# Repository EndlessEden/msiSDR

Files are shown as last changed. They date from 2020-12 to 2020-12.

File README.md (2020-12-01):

this is an Software Define Radio receiver PCB project base on msi2500 and msi001. use kicad to view it

这是一个基于msi2500 和 msi001的软件无线电PCB工程项目， 使用kiCAD浏览此工程

如果需要PCB打样，把gerber目录下的文件发给PCB加工厂即可

Send gerbar files to PCB factory . you'd better to use SMT

建议叫工厂SMT贴片，手动焊接容易太多bug

软件使用SDRuno（选SDRPlay）

software compatible with SDRplay

## Updates from NaiveTomcat
在原版的基础上增加了一个U.FL接口用于L波段天线的连接（才不会说是懒得重新
布线才用U.FL接口的呢）Gerber文件在Gerberv3目录

Added a U.FL Male socket onto the PCB for aerials for L-Band.
(Used U.FL for its size can fit inside the board with no need
to redo the route) Gerber files are in the Gerberv3 directory.

使用效果

PCB

SDR

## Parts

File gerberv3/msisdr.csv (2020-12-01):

ID | 位号 | 包 | 数量 | 名称 | 供应商和位号
1 | J12 | U.FL_Molex_MCRF_73412-0110_Vertical | 1 | Conn_01x02
2 | C43 | C_0603_1608Metric_Pad1.08x0.95mm_HandSolder | 1 | 10nF
3 | REF**,REF**,REF**,REF** | 1pin | 4 | 1pin
4 | C1,C11,C12,C13,C14,C15,C19,C20,C21,C24,C25,C26,C42 | C_0603 | 13 | 10nF
5 | C2,C3,C4,C5,C7,C36,C37,C38 | C_0805 | 8 | 10uF
6 | C6,C8,C18 | C_0805 | 3 | 1uF
7 | C9,C10 | C_0603 | 2 | 18pF
8 | C16,C17 | C_0603 | 2 | 100nF
9 | C22 | C_0603 | 1 | 6800pF
10 | C23 | C_0603 | 1 | 33nF
11 | C27 | C_0805 | 1 | 470nF
12 | C28 | C_0603 | 1 | 1nF
13 | C29,C34 | C_0603 | 2 | 56pF
14 | C30 | C_0603 | 1 | 3.9pF
15 | C31,C33 | C_0603 | 2 | 160pF
16 | C32 | C_0603 | 1 | 39pF
17 | C35 | CP_Radial_D5.0mm_P2.50mm | 1 | 100uF
18 | J6 | SMA_OPL_EM | 1 | SMA_0_30MHZ
19 | J7 | SMA_OPL_EM | 1 | SMA_30_60MHZ
20 | J8 | SMA_OPL_EMPTYHEAD | 1 | SMA_VHF2
21 | J9 | SMA_OPL_EMPTYHEAD | 1 | SMA_UHF
22 | J10 | SMA_OPL_EMPTYHEAD | 1 | SMA_VHF1
23 | J11 | USB_Mini-B | 1 | USB_OTG
24 | L1 | L_0805 | 1 | 220nH
25 | L2,L3,L6 | L_0805 | 3 | 330nH
26 | L4 | L_0805 | 1 | 270nH
27 | L5 | L_0805 | 1 | 150nH
28 | R1 | R_0603 | 1 | 510R
29 | R2 | R_0603 | 1 | 390R
30 | U1 | QFN-32-1EP_5x5mm_Pitch0.5mm | 1 | msi2500
31 | U2 | QFN-40-1EP_6x6mm_Pitch0.5mm | 1 | msi001
32 | Y1 | Crystal_HC50_Vertical | 1 | 24MHz
33 | J1 | Pin_d0.7mm_L6.5mm_W1.8mm_FlatFork | 1 | VCC_GPIO
34 | J2 | Pin_d0.7mm_L6.5mm_W1.8mm_FlatFork | 1 | GPIO0
35 | J3 | Pin_d0.7mm_L6.5mm_W1.8mm_FlatFork | 1 | GPIO1
36 | J4 | Pin_d0.7mm_L6.5mm_W1.8mm_FlatFork | 1 | GPIO2
37 | J5 | Pin_d0.7mm_L6.5mm_W1.8mm_FlatFork | 1 | GPIO3
38 | C39,C41 | C_0805 | 2 | 1UF
39 | D5 | D_DO-35_SOD27_P2.54mm_Vertical_AnodeUp | 1 | LED
40 | R3 | R_0603 | 1 | 512
41 | C40 | C_0603 | 1 | 22nF
42 | R4,R5,R6,R7,R8 | R_0603 | 5 | 10K
43 | U3 | SOT-23-5 | 1 | RT9193-28
44 | U4 | SOT-23 | 1 | AP7313-30SAG
45 | Y2 | Crystal_SMD_7050-4pin_7.0x5.0mm | 1 | 24MHZ
46 | D1,D2 | SOT-23 | 2 | BAV99LT1G
47 | REF*** | KiCad-Logo2_6mm_SilkScreen | 1 | KiCad-Logo2_6mm_SilkScreen
48 | REF*** | WEEE-Logo_5.6x8mm_SilkScreen | 1 | WEEE-Logo_5.6x8mm_SilkScreen

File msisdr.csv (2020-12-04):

ID | 位号 | 包 | 数量 | 名称 | 供应商和位号
1 | J10 | SMA_Samtec_SMA-J-P-X-ST-EM1_EdgeMount | 1 | SMA_VHF1
2 | J8 | SMA_Samtec_SMA-J-P-X-ST-EM1_EdgeMount | 1 | SMA_VHF2
3 | Y2 | Crystal_SMD_7050-4Pin_7.0x5.0mm | 1 | 24MHZ
4 | Y1 | Crystal_HC50_Vertical | 1 | 24MHz
5 | U4 | SOT-23 | 1 | AP7313-30SAG
6 | U3 | SOT-23-5 | 1 | RT9193-28
7 | U2 | QFN-40-1EP_6x6mm_P0.5mm_EP4.6x4.6mm_ThermalVias | 1 | msi001
8 | U1 | QFN-32-1EP_5x5mm_P0.5mm_EP3.7x3.7mm_ThermalVias | 1 | msi2500
9 | R8,R7,R6,R5,R4 | R_1206_3216Metric_Pad1.30x1.75mm_HandSolder | 5 | 10K
10 | R3 | R_1206_3216Metric_Pad1.30x1.75mm_HandSolder | 1 | 512
11 | R2 | R_1206_3216Metric_Pad1.30x1.75mm_HandSolder | 1 | 390R
12 | R1 | R_1206_3216Metric_Pad1.30x1.75mm_HandSolder | 1 | 510R
13 | L6,L3,L2 | L_1206_3216Metric_Pad1.42x1.75mm_HandSolder | 3 | 330nH
14 | L5 | L_1206_3216Metric_Pad1.42x1.75mm_HandSolder | 1 | 150nH
15 | L4 | L_1206_3216Metric_Pad1.42x1.75mm_HandSolder | 1 | 270nH
16 | L1 | L_1206_3216Metric_Pad1.42x1.75mm_HandSolder | 1 | 220nH
17 | J11 | USB_Micro-B_Wuerth_629105150521 | 1 | USB_OTG
18 | J9 | SMA_Samtec_SMA-J-P-X-ST-EM1_EdgeMount | 1 | SMA_UHF
19 | J7 | SMA_Samtec_SMA-J-P-X-ST-EM1_EdgeMount | 1 | SMA_30_60MHZ
20 | J6 | SMA_Samtec_SMA-J-P-X-ST-EM1_EdgeMount | 1 | SMA_0_30MHZ
21 | J5 | Pin_D0.7mm_L6.5mm_W1.8mm_FlatFork | 1 | GPIO3
22 | J4 | Pin_D0.7mm_L6.5mm_W1.8mm_FlatFork | 1 | GPIO2
23 | J3 | Pin_D0.7mm_L6.5mm_W1.8mm_FlatFork | 1 | GPIO1
24 | J2 | Pin_D0.7mm_L6.5mm_W1.8mm_FlatFork | 1 | GPIO0
25 | J1 | Pin_D0.7mm_L6.5mm_W1.8mm_FlatFork | 1 | VCC_GPIO
26 | D5 | D_DO-35_SOD27_P2.54mm_Vertical_AnodeUp | 1 | LED
27 | D2,D1 | SOT-23 | 2 | BAV99LT1G
28 | C43,C42,C26,C25,C24,C21,C20,C19,C15,C14,C13,C12,C11,C1 | C_1206_3216Metric_Pad1.33x1.80mm_HandSolder | 14 | 10nF
29 | C41,C39 | C_1206_3216Metric_Pad1.33x1.80mm_HandSolder | 2 | 1UF
30 | C40 | C_1206_3216Metric_Pad1.33x1.80mm_HandSolder | 1 | 22nF
31 | C38,C37,C36,C7,C5,C4,C3,C2 | C_1206_3216Metric_Pad1.33x1.80mm_HandSolder | 8 | 10uF
32 | C35 | CP_Radial_D5.0mm_P2.50mm | 1 | 100uF
33 | C34,C29 | C_1206_3216Metric_Pad1.33x1.80mm_HandSolder | 2 | 56pF
34 | C33,C31 | C_1206_3216Metric_Pad1.33x1.80mm_HandSolder | 2 | 160pF
35 | C32 | C_1206_3216Metric_Pad1.33x1.80mm_HandSolder | 1 | 39pF
36 | C30 | C_1206_3216Metric_Pad1.33x1.80mm_HandSolder | 1 | 3.9pF
37 | C28 | C_1206_3216Metric_Pad1.33x1.80mm_HandSolder | 1 | 1nF
38 | C27 | C_1206_3216Metric_Pad1.33x1.80mm_HandSolder | 1 | 470nF
39 | C23 | C_1206_3216Metric_Pad1.33x1.80mm_HandSolder | 1 | 33nF
40 | C22 | C_1206_3216Metric_Pad1.33x1.80mm_HandSolder | 1 | 6800pF
41 | C18,C8,C6 | C_1206_3216Metric_Pad1.33x1.80mm_HandSolder | 3 | 1uF
42 | C17,C16 | C_1206_3216Metric_Pad1.33x1.80mm_HandSolder | 2 | 100nF
43 | C10,C9 | C_1206_3216Metric_Pad1.33x1.80mm_HandSolder | 2 | 18pF
44 | J12 | U.FL_Molex_MCRF_73412-0110_Vertical | 1 | Conn_01x02
45 | REF**,REF**,REF**,REF** | 1pin | 4 | 1pin

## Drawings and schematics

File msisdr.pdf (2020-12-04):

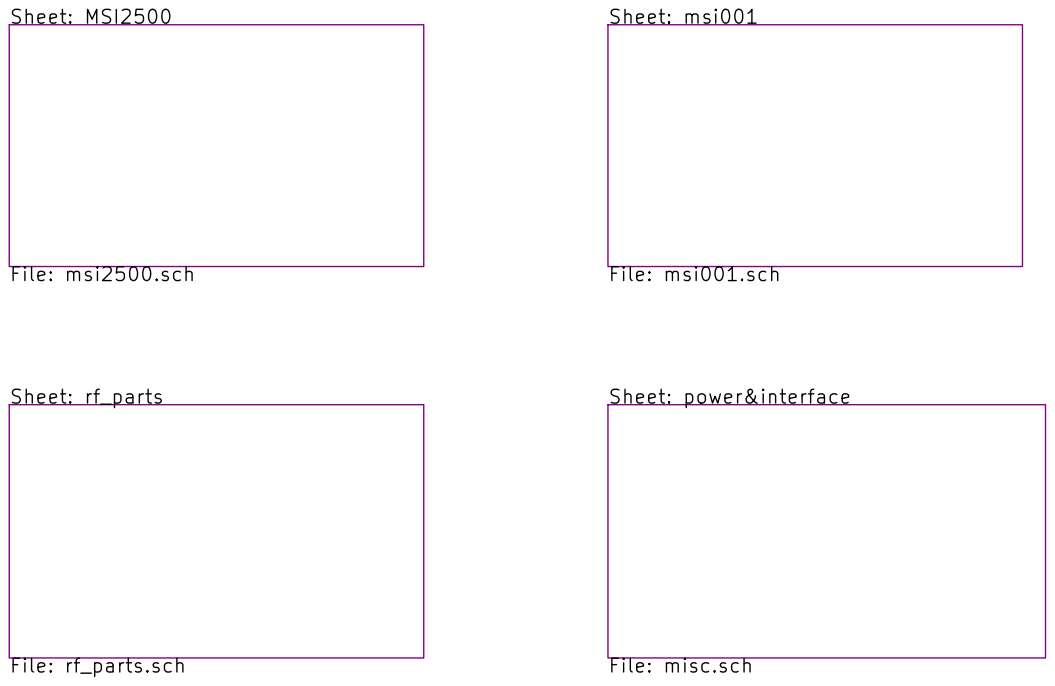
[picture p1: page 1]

Sheet: power&interface File: misc.sch

Id: 1/5 Title: File: msisdr.sch Sheet: /

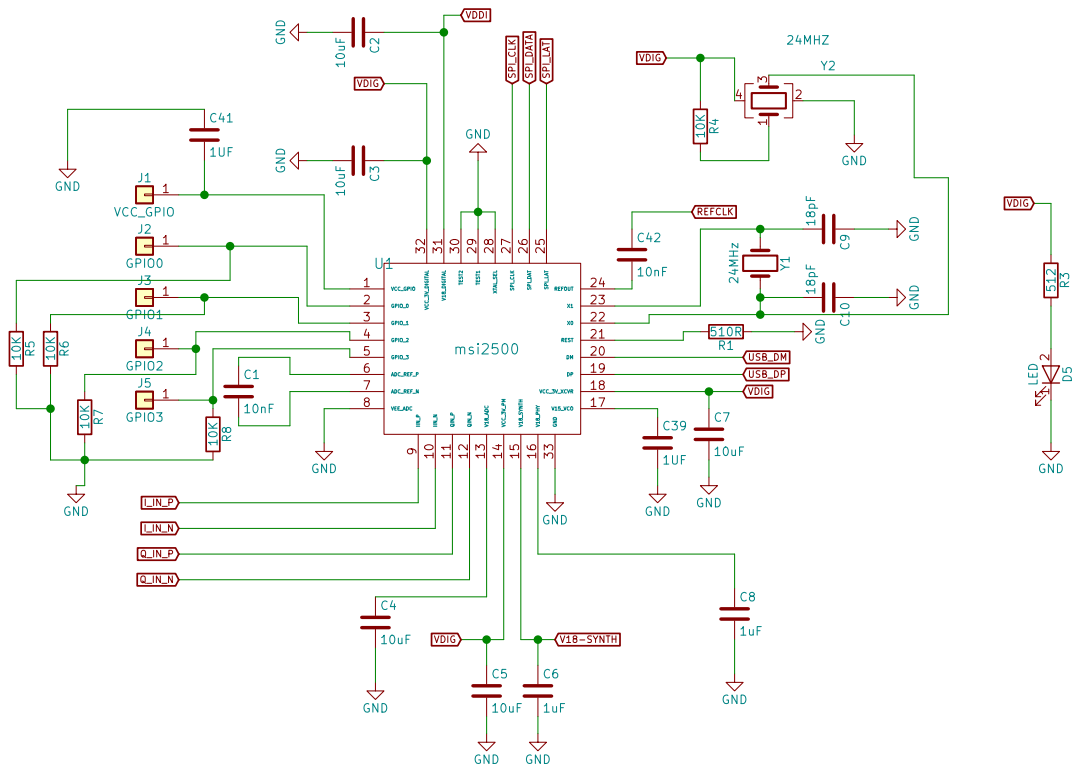
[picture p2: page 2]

Id: 2/5 Title: File: msi2500.sch Sheet: /MSI2500/ C6

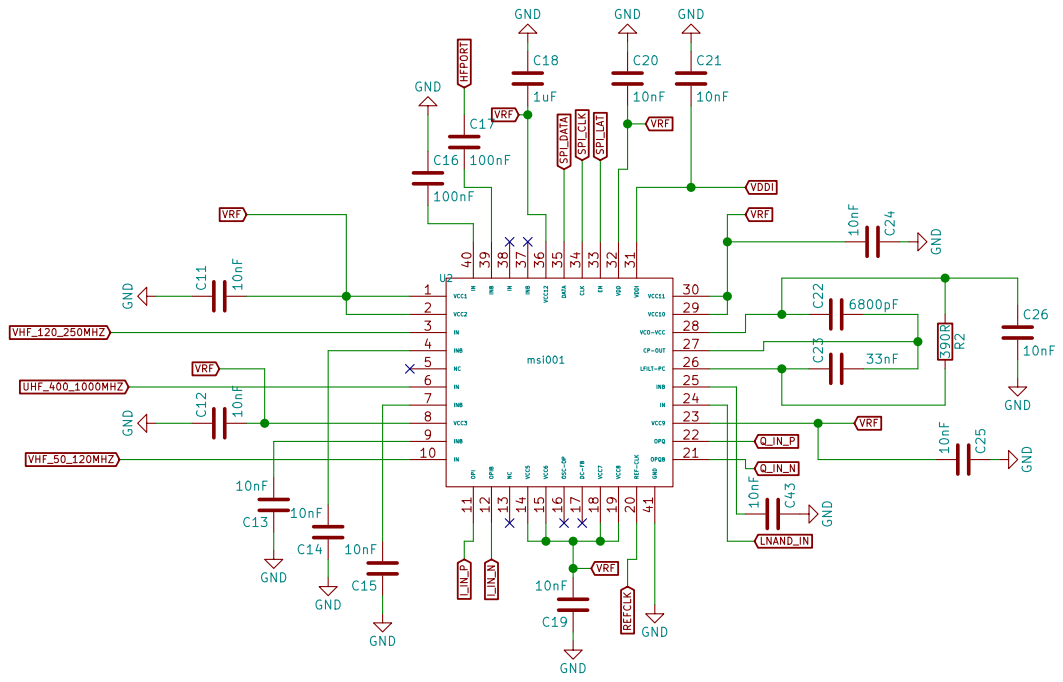
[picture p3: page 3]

Id: 3/5 Title: File: msi001.sch Sheet: /msi001/

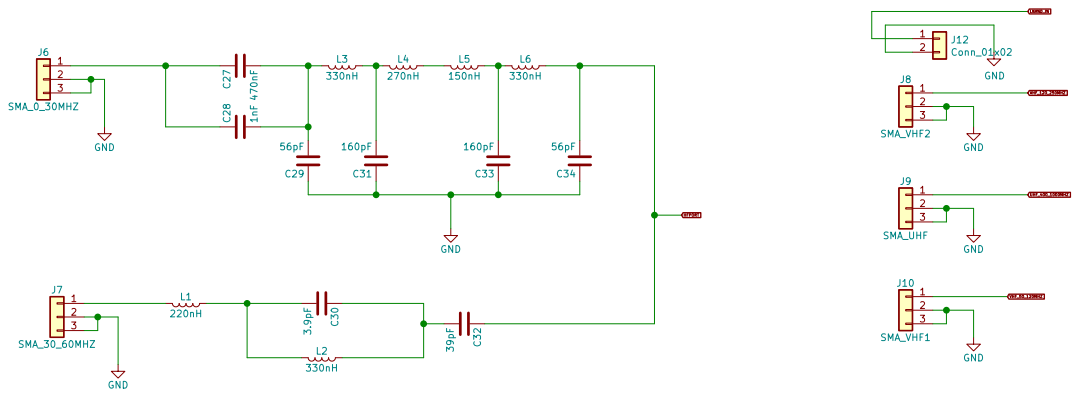
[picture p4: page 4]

2 | 470nF 56pF C27

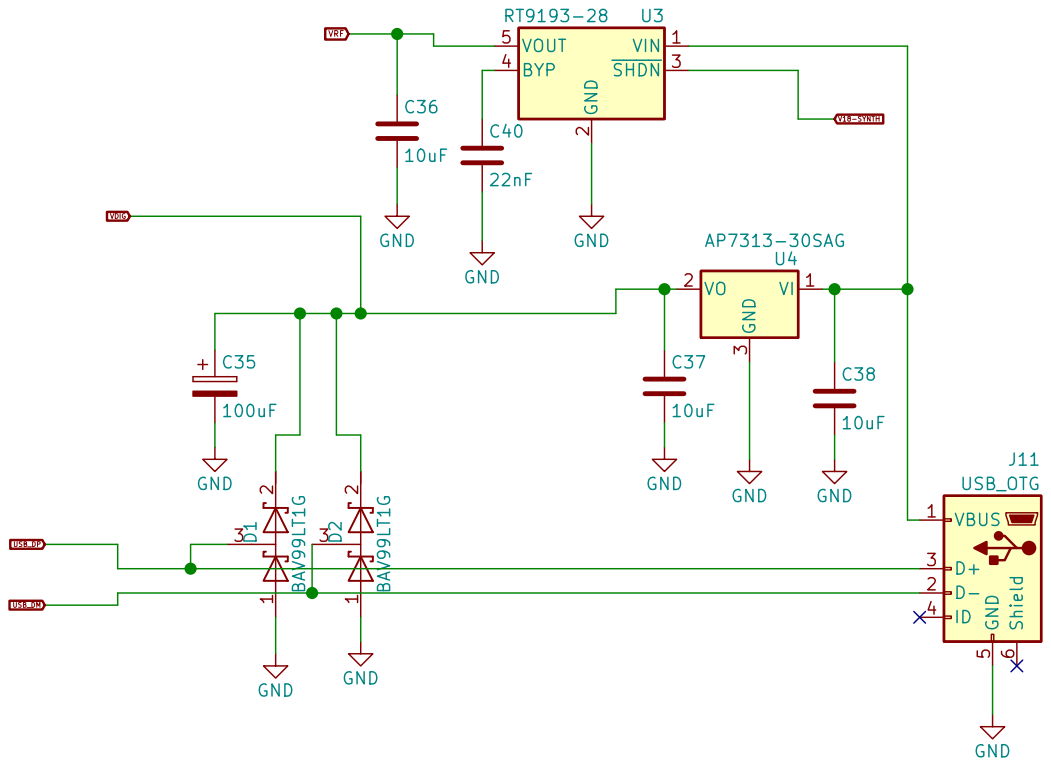
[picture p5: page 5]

2 SHDN 3 BYP 4 VOUT 5 RT9193-28 U3 VI 1 VO 2 GND

Id: 5/5 Title: File: misc.sch Sheet: /power&interface/ GND GND

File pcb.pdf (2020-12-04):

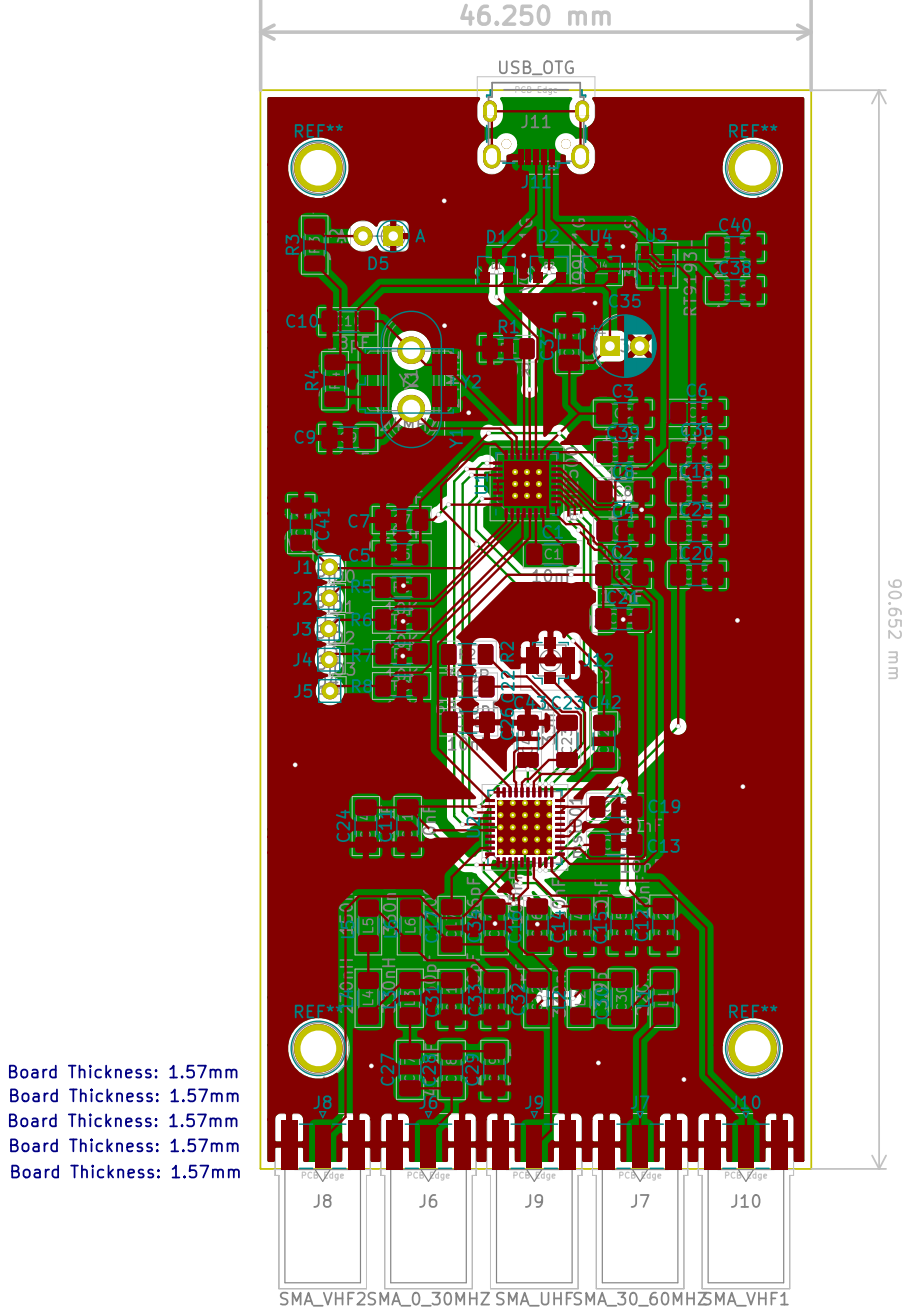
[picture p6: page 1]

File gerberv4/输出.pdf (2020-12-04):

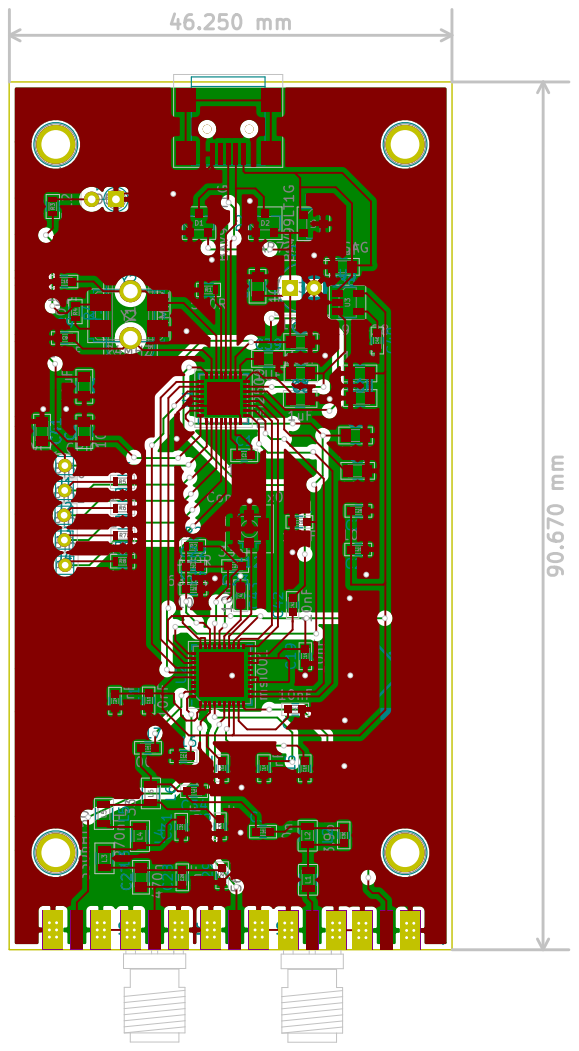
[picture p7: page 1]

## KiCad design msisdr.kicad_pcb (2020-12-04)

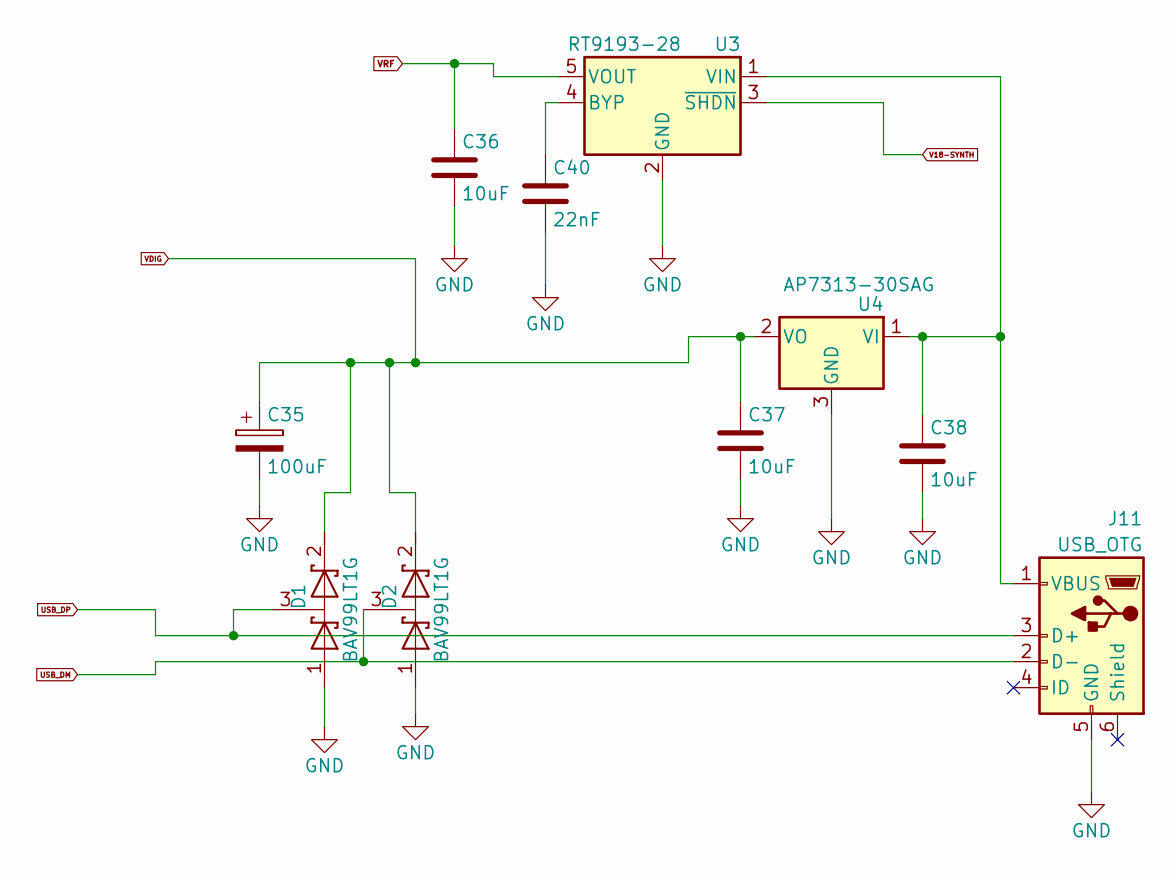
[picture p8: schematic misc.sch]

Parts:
C35: 100uF; CP_Radial_D5.0mm_P2.50mm
C36, C37, C38: 10uF; C_1206_3216Metric_Pad1.33x1.80mm_HandSolder
C40: 22nF; C_1206_3216Metric_Pad1.33x1.80mm_HandSolder
D1, D2: BAV99LT1G; SOT-23
J11: USB_OTG; USB_Micro-B_Wuerth_629105150521
U3: RT9193-28; SOT-23-5
U4: AP7313-30SAG; SOT-23

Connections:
GND: C35.2, C36.2, C37.2, C38.2, C40.2, D1.1 (A), D2.1 (A), J11.5 (GND), U3.2 (GND), U4.3 (GND); also elsewhere on the board
unnamed: C38.1, J11.1 (VBUS), U3.1 (VIN), U4.1 (VI)
unnamed: C40.1, U3.4 (BYP)
USB_DM: D2.3 (common), J11.2 (D-); also elsewhere on the board
USB_DP: D1.3 (common), J11.3 (D+); also elsewhere on the board
V18-SYNTH: U3.3 (~SHDN~); also elsewhere on the board
VDIG: C35.1, C37.1, D1.2 (K), D2.2 (K), U4.2 (VO); also elsewhere on the board
VRF: C36.1, U3.5 (VOUT); also elsewhere on the board

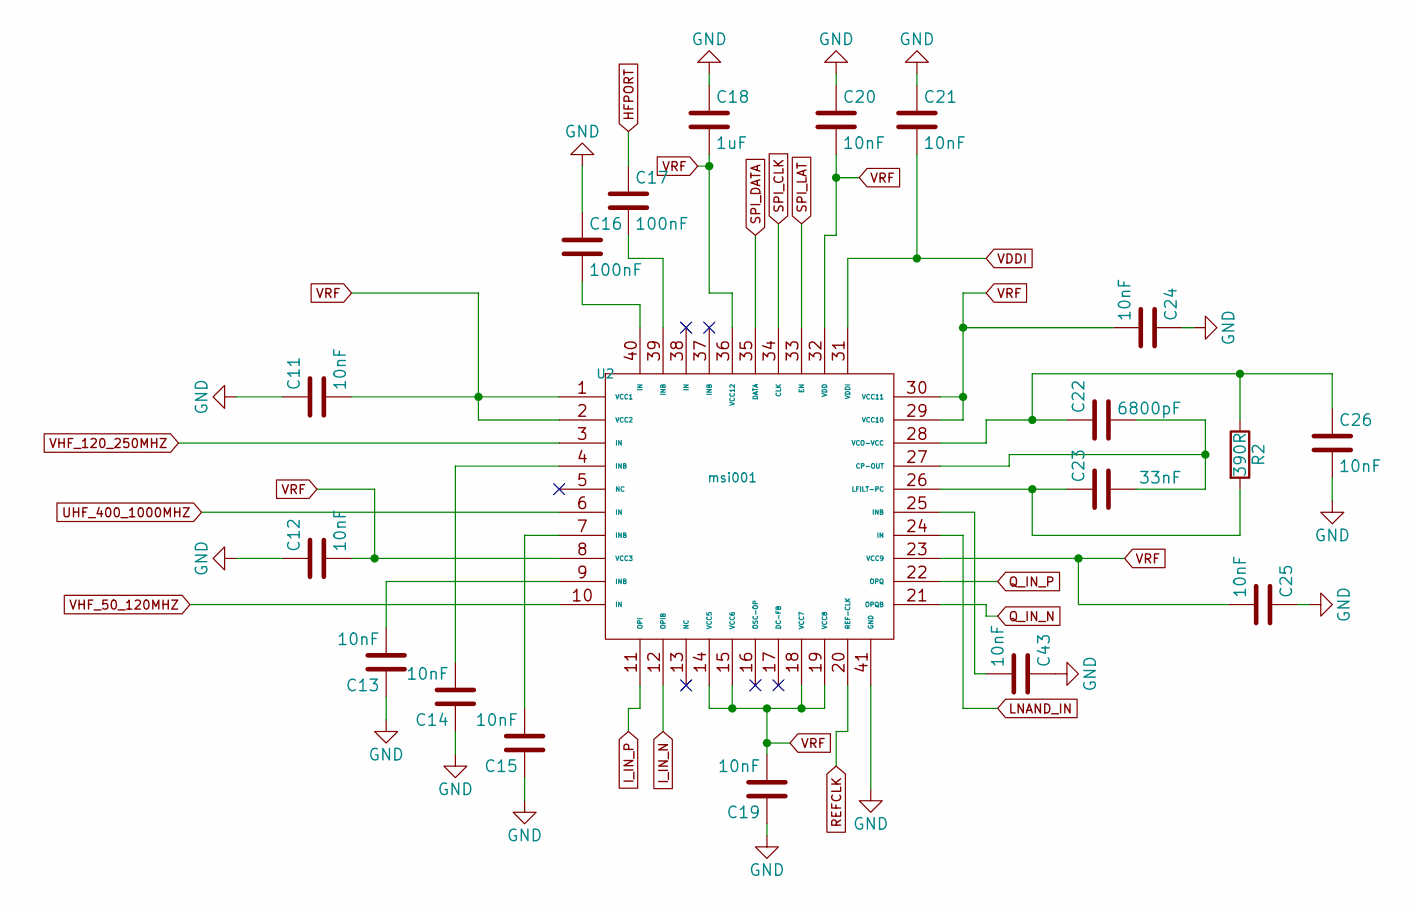
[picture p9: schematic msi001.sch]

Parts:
C11, C12, C13, C14, C15, C19, C20, C21, C24, C25, C26, C43: 10nF; C_1206_3216Metric_Pad1.33x1.80mm_HandSolder
C16, C17: 100nF; C_1206_3216Metric_Pad1.33x1.80mm_HandSolder
C18: 1uF; C_1206_3216Metric_Pad1.33x1.80mm_HandSolder
C22: 6800pF; C_1206_3216Metric_Pad1.33x1.80mm_HandSolder
C23: 33nF; C_1206_3216Metric_Pad1.33x1.80mm_HandSolder
R2: 390R; R_1206_3216Metric_Pad1.30x1.75mm_HandSolder
U2: msi001; QFN-40-1EP_6x6mm_P0.5mm_EP4.6x4.6mm_ThermalVias

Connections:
GND: C11.1, C12.1, C13.1, C14.1, C15.1, C16.1, C18.1, C19.1, C20.1, C21.1, C24.1, C25.1, C26.2, C43.1, U2.41 (GND); also elsewhere on the board
HFPORT: C17.1; also elsewhere on the board
I_IN_N: U2.12 (OPIB); also elsewhere on the board
I_IN_P: U2.11 (OPI); also elsewhere on the board
LNAND_IN: U2.24 (IN); also elsewhere on the board
unnamed: C13.2, U2.9 (INB)
unnamed: C14.2, U2.4 (INB)
unnamed: C15.2, U2.7 (INB)
unnamed: C16.2, U2.40 (IN)
unnamed: C17.2, U2.39 (INB)
unnamed: C22.1, C26.1, R2.1, U2.28 (VCO-VCC)
unnamed: C22.2, C23.2, U2.27 (CP-OUT)
unnamed: C23.1, R2.2, U2.26 (LFILT-PC)
unnamed: C43.2, U2.25 (INB)
Q_IN_N: U2.21 (OPQB); also elsewhere on the board
Q_IN_P: U2.22 (OPQ); also elsewhere on the board
REFCLK: U2.20 (REF-CLK); also elsewhere on the board
SPI_CLK: U2.34 (CLK); also elsewhere on the board
SPI_DATA: U2.35 (DATA); also elsewhere on the board
SPI_LAT: U2.33 (EN); also elsewhere on the board
UHF_400_1000MHZ: U2.6 (IN); also elsewhere on the board
VDDI: C21.2, U2.31 (VDDI); also elsewhere on the board
VHF_50_120MHZ: U2.10 (IN); also elsewhere on the board
VHF_120_250MHZ: U2.3 (IN); also elsewhere on the board
VRF: C11.2, C12.2, C18.2, C19.2, C20.2, C24.2, C25.2, U2.1 (VCC1), U2.2 (VCC2), U2.8 (VCC3), U2.14 (VCC5), U2.15 (VCC6), U2.18 (VCC7), U2.19 (VCC8), U2.23 (VCC9), U2.29 (VCC10), U2.30 (VCC11), U2.32 (VDD), U2.36 (VCC12); also elsewhere on the board

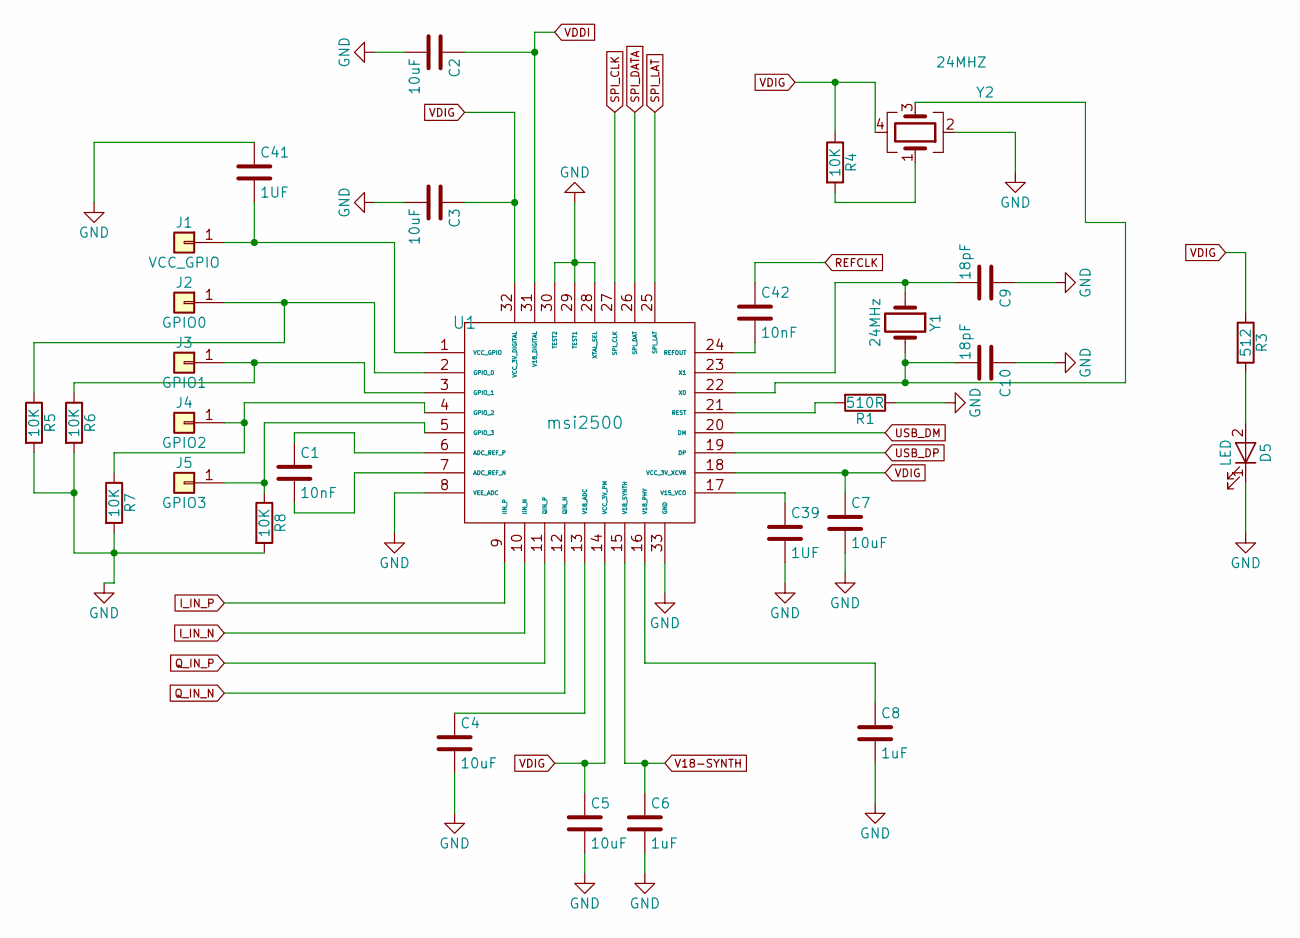
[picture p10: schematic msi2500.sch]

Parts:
C1, C42: 10nF; C_1206_3216Metric_Pad1.33x1.80mm_HandSolder
C2, C3, C4, C5, C7: 10uF; C_1206_3216Metric_Pad1.33x1.80mm_HandSolder
C6, C8: 1uF; C_1206_3216Metric_Pad1.33x1.80mm_HandSolder
C9, C10: 18pF; C_1206_3216Metric_Pad1.33x1.80mm_HandSolder
C39, C41: 1UF; C_1206_3216Metric_Pad1.33x1.80mm_HandSolder
D5: LED; D_DO-35_SOD27_P2.54mm_Vertical_AnodeUp
J1: VCC_GPIO; Pin_D0.7mm_L6.5mm_W1.8mm_FlatFork
J2: GPIO0; Pin_D0.7mm_L6.5mm_W1.8mm_FlatFork
J3: GPIO1; Pin_D0.7mm_L6.5mm_W1.8mm_FlatFork
J4: GPIO2; Pin_D0.7mm_L6.5mm_W1.8mm_FlatFork
J5: GPIO3; Pin_D0.7mm_L6.5mm_W1.8mm_FlatFork
R1: 510R; R_1206_3216Metric_Pad1.30x1.75mm_HandSolder
R3: 512; R_1206_3216Metric_Pad1.30x1.75mm_HandSolder
R4, R5, R6, R7, R8: 10K; R_1206_3216Metric_Pad1.30x1.75mm_HandSolder
U1: msi2500; QFN-32-1EP_5x5mm_P0.5mm_EP3.7x3.7mm_ThermalVias
Y1: 24MHz; Crystal_HC50_Vertical
Y2: 24MHZ; Crystal_SMD_7050-4Pin_7.0x5.0mm

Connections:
GND: C2.2, C3.2, C4.2, C5.2, C6.2, C7.2, C8.2, C9.1, C10.1, C39.2, C41.1, D5.1 (K), R1.1, R5.2, R6.2, R7.2, R8.2, U1.8 (VEE_ADC), U1.28 (XTAL_SEL), U1.29 (TEST1), U1.30 (TEST2), U1.33 (GND), Y2.2; also elsewhere on the board
I_IN_N: U1.10 (IIN_N); also elsewhere on the board
I_IN_P: U1.9 (IIN_P); also elsewhere on the board
unnamed: C1.1, U1.6 (ADC_REF_P)
unnamed: C1.2, U1.7 (ADC_REF_N)
unnamed: C4.1, U1.13 (V18_ADC)
unnamed: C8.1, U1.16 (V18_PHY)
unnamed: C9.2, U1.23 (X1), Y1.1
unnamed: C10.2, U1.22 (X0), Y1.2, Y2.3
unnamed: C39.1, U1.17 (V15_VCO)
unnamed: C41.2, J1.1, U1.1 (VCC_GPIO)
unnamed: C42.2, U1.24 (REFOUT)
unnamed: D5.2 (A), R3.2
unnamed: J2.1, R5.1, U1.2 (GPIO_0)
unnamed: J3.1, R6.1, U1.3 (GPIO_1)
unnamed: J4.1, R7.1, U1.4 (GPIO_2)
unnamed: J5.1, R8.1, U1.5 (GPIO_3)
unnamed: R1.2, U1.21 (REST)
unnamed: R4.2, Y2.1
Q_IN_N: U1.12 (QIN_N); also elsewhere on the board
Q_IN_P: U1.11 (QIN_P); also elsewhere on the board
REFCLK: C42.1; also elsewhere on the board
SPI_CLK: U1.27 (SPI_CLK); also elsewhere on the board
SPI_DATA: U1.26 (SPI_DAT); also elsewhere on the board
SPI_LAT: U1.25 (SPI_LAT); also elsewhere on the board
USB_DM: U1.20 (DM); also elsewhere on the board
USB_DP: U1.19 (DP); also elsewhere on the board
V18-SYNTH: C6.1, U1.15 (V18_SYNTH); also elsewhere on the board
VDDI: C2.1, U1.31 (V18_DIGITAL); also elsewhere on the board
VDIG: C3.1, C5.1, C7.1, R3.1, R4.1, U1.14 (VCC_3V_PM), U1.18 (VCC_3V_XCVR), U1.32 (VCC_3V_DIGITAL), Y2.4; also elsewhere on the board

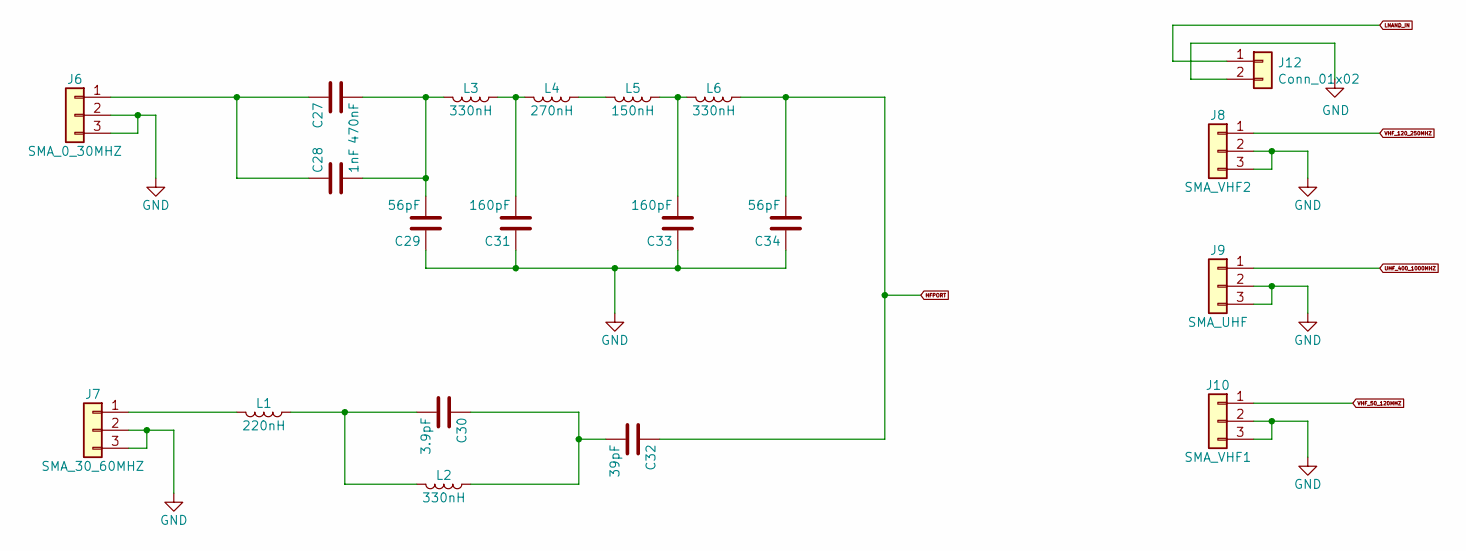
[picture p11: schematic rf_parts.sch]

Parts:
C27: 470nF; C_1206_3216Metric_Pad1.33x1.80mm_HandSolder
C28: 1nF; C_1206_3216Metric_Pad1.33x1.80mm_HandSolder
C29, C34: 56pF; C_1206_3216Metric_Pad1.33x1.80mm_HandSolder
C30: 3.9pF; C_1206_3216Metric_Pad1.33x1.80mm_HandSolder
C31, C33: 160pF; C_1206_3216Metric_Pad1.33x1.80mm_HandSolder
C32: 39pF; C_1206_3216Metric_Pad1.33x1.80mm_HandSolder
J6: SMA_0_30MHZ; SMA_Samtec_SMA-J-P-X-ST-EM1_EdgeMount
J7: SMA_30_60MHZ; SMA_Samtec_SMA-J-P-X-ST-EM1_EdgeMount
J8: SMA_VHF2; SMA_Samtec_SMA-J-P-X-ST-EM1_EdgeMount
J9: SMA_UHF; SMA_Samtec_SMA-J-P-X-ST-EM1_EdgeMount
J10: SMA_VHF1; SMA_Samtec_SMA-J-P-X-ST-EM1_EdgeMount
J12: Conn_01x02; U.FL_Molex_MCRF_73412-0110_Vertical
L1: 220nH; L_1206_3216Metric_Pad1.42x1.75mm_HandSolder
L2, L3, L6: 330nH; L_1206_3216Metric_Pad1.42x1.75mm_HandSolder
L4: 270nH; L_1206_3216Metric_Pad1.42x1.75mm_HandSolder
L5: 150nH; L_1206_3216Metric_Pad1.42x1.75mm_HandSolder

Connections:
GND: C29.1, C31.1, C33.1, C34.1, J6.2, J6.3, J7.2, J7.3, J8.2, J8.3, J9.2, J9.3, J10.2, J10.3, J12.2; also elsewhere on the board
HFPORT: C32.1, C34.2, L6.1; also elsewhere on the board
LNAND_IN: J12.1; also elsewhere on the board
unnamed: C27.1, C28.1, J6.1
unnamed: C27.2, C28.2, C29.2, L3.2
unnamed: C30.1, C32.2, L2.1
unnamed: C30.2, L1.1, L2.2
unnamed: C31.2, L3.1, L4.2
unnamed: C33.2, L5.1, L6.2
unnamed: J7.1, L1.2
unnamed: L4.1, L5.2
UHF_400_1000MHZ: J9.1; also elsewhere on the board
VHF_50_120MHZ: J10.1; also elsewhere on the board
VHF_120_250MHZ: J8.1; also elsewhere on the board

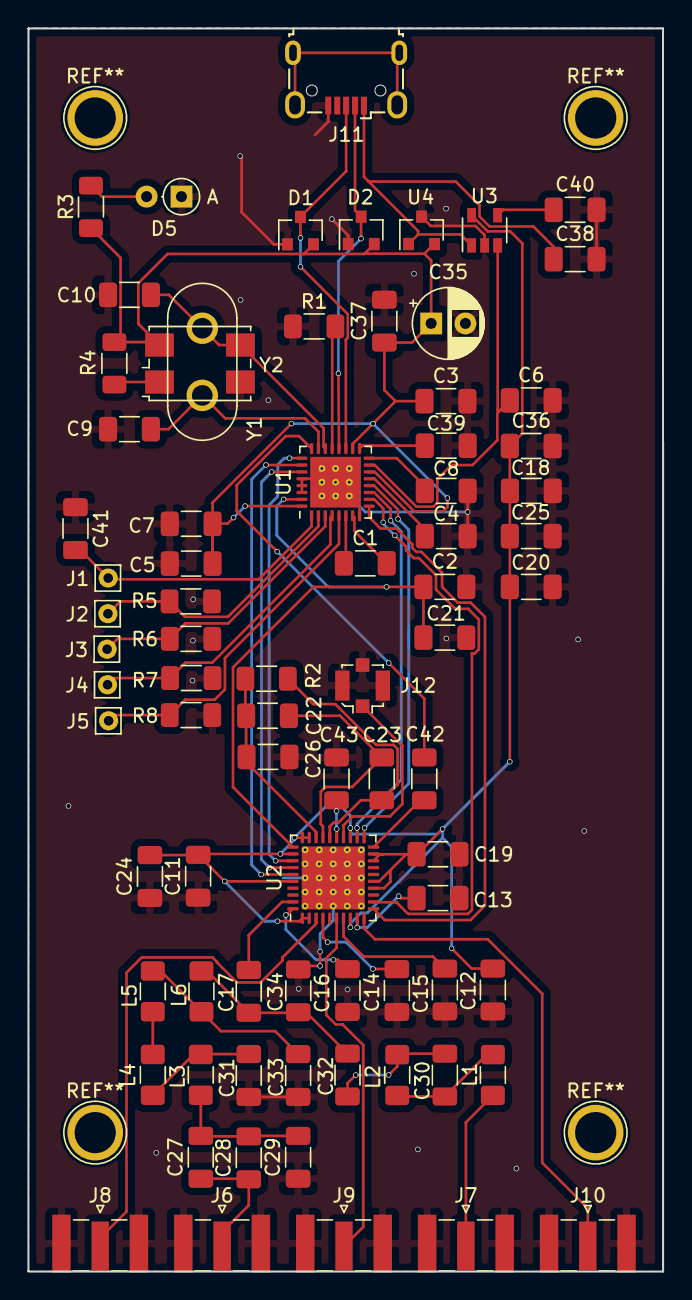
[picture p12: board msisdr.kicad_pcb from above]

Board: 2 copper layers, 46.3 x 90.7 mm, 78 parts (0 on the bottom side), 55 nets.

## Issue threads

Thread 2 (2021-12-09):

RSP1C (RSP1-C?)

EndlessEden, 2021-12-09:
As noted by user u/Iomotap on reddit. A possible variant of RSP1-F exists in the wild, which the vendor has dubbed "RSP1C".  (https://www.aliexpress.com/item/1005003582765124.html)

the product differs from the RSP1-F's design and more closely resembles SDRplays RSP1, even more than the other initial clones. | further reviewing of information necessary to determine if it is in fact a variant or a clone of RSP1-F.

Product Images (Direct)
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

EndlessEden, 2021-12-09:
notes: https://www.reddit.com/r/RTLSDR/comments/onftps/any_feedback_on_the_bg7yzf_version_of_the_msi_001/hnt3qxa/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

patomoi, 2021-12-10:
hi i have continued with my research and probably i found the "forks" of the proyect by smith in the chinese page Kechuang:

https://www.kechuang.org/t/85213 this would be the genesis of the "simple version", in the comments are the progression of the proyect

https://www.kechuang.org/t/85043 this would be the beggining of the RSP1C

https://www.kechuang.org/t/86356 this is probably the  early version of the "full version" is based

seems to be a active community in this sdr type, even in the comments the same makers and engineers (including smith) make comments and suggestions

maybe BG7YZF look at these post and merge ideas and designs, and using their university installations made the 2 variants know by ours now

see ya. 73 de CA2PEY

patomoi, 2022-01-14:
hi, i have purchased the RSPc and the performance is amazing, in fact the software recognizes it like rsp1 and is way better than my RTL-SDR.

patomoi, 2022-01-22:
hi this vendor is offering simple version with case https://es.aliexpress.com/item/1005003802073340.html

FrankHovis, 2022-07-07:
I'm guessing this is yet another attempt at a redesign around the same chipset https://www.ebay.co.uk/itm/304499324587

patomoi, 2022-07-17:
> I'm guessing this is yet another attempt at a redesign around the same chipset https://www.ebay.co.uk/itm/304499324587

this seems to be an upgrade over the first models of MSI.SDR (the blue dolphin one). interesting, une can see the path in the traces, i think this model would be great for a fixed online sdr station.

kelogs, 2024-05-25:
> I'm guessing this is yet another attempt at a redesign around the same chipset https://www.ebay.co.uk/itm/304499324587

I am trying to decide between this one and the RSP1C. This one clearly has the bandpass filters. Does the RSP1C also have them ?

Looking to use it with GQRX, so even if the RSP1C does have the filters, I guess they will not be used as GQRX is not SDRuno  (and the public API does not expose any ways of activating them)?

Any other comments welcome. Thanks!

patomoi, 2024-07-05:
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

hi, the rsp1c  have the filters, the filters are activated by the chip, the uncased model have reviews of  fault in the microswitches and sma connector.

kelogs, 2024-07-22:
> hi, the rsp1c have the filters, the filters are activated by the chip, the uncased model have reviews of fault in the microswitches and sma connector.

It does not look that the RSP1C has those API addressable filters:

randy@raspberrypi:~ $ SoapySDRUtil --probe=sdrplay
######################################################
## Soapy SDR -- the SDR abstraction library
######################################################

Probe device sdrplay

----------------------------------------------------
-- Device identification
----------------------------------------------------
  driver=SDRplay
  hardware=RSP1
  mir_sdr_api_version=2.130000
  mir_sdr_hw_version=1
  serial=B0001P0005

----------------------------------------------------
-- Peripheral summary
----------------------------------------------------
  Channels: 1 Rx, 0 Tx
  Timestamps: NO
  Other Settings:
     * RF Gain Select - RF Gain Select
       [key=rfgain_sel, default=1, type=string, options=(0, 1, 2, 3)]
     * IF Mode - IF frequency in kHz
       [key=if_mode, default=Zero-IF, type=string, options=(Zero-IF, 450kHz, 1620kHz, 2048kHz)]
     * IQ Correction - IQ Correction Control
       [key=iqcorr_ctrl, default=true, type=bool]
     * AGC Setpoint - AGC Setpoint (dBfs)
       [key=agc_setpoint, default=-30, type=int, range=[-60, 0]]

No mention of

* RfNotch Enable - RF Notch Filter Control
[key=rfnotch_ctrl, default=true, type=bool]
* DabNotch Enable - DAB Notch Filter Control
[key=dabnotch_ctrl, default=true, type=bool]

If it does have any filters, then what sort of filters does it have and are they controllable ?

Thanks

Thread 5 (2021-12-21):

Transcription issue

NaiveTomcat, 2021-12-21:
> The "SDR RSP1 Simple" design originates from Huanghuai University(MAKER SPACE OF HUANGHUAI UNIVERSITY[香港 创 客 空 闪])(* See HHU), research done by a member known as "Smith" on their "Domestic science and technology forum" (See Design). The SDR RSP1's are improvements to these designs by "BG7YZF". A self-described as "a computer science and technology undergraduate student who is engaged in radio, model aircraft, drone, and photography." on their vendor page.

It appears that the transcription "香港 创 客 空 闪" is not correct. It should be "黄淮创客空间".

EndlessEden, 2022-01-14:
Thank you so much! - English is my native language, so i had no point of reference. ill update ASAP ^_^

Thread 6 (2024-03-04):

Full version type of antenna connector

michelinok, 2024-03-04:
Hi!
I'm asking for help here because I have not found another place where to ask...
What kind of antenna connector is soldered of the "full version"? male sma or female sma?

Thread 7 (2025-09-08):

How to fix HF signal ?

Yag00000, 2025-09-08:
All band works fine except 0-30 , 30-60 Mhz :-(

Drakepirate, 2025-09-18:
It happen to me the same. Tried to use antenna amplifier after that. it won't work. The rest is ok. Burnt MSI001?

Drakepirate, 2025-09-24:
Bueno, a la peor, se puede comprar otra placa u oro chip. Aquí son baratos...

Yag00000, 2025-09-24:
Me gustaría repararlo se oía muy bien salvo el gap entre 250-400Mhz que no recibe nada de serie

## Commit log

2020-12-01 Added an U.FL male socket for L Band antanae
    [misc-2020-12-01-16-32-17.sch, misc-2020-12-01-22-29-58.sch, msi001-2020-12-01-16-32-17.sch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]
2020-12-02 Fixed clearance issue
    [msisdr-B_Adhes.gbr, msisdr-B_Cu.gbr, msisdr-B_Mask.gbr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]
2020-12-04 Changed the package of R, C and L to 1206 for hand soldering.
    [misc.sch, msi001.sch, msi2500.sch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]
2020-12-04 Added gerber files
    [msisdr-B_Adhes.gbr, msisdr-B_Cu.gbr, msisdr-B_Mask.gbr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]
2020-12-04 added bom
    [msisdr.csv]
